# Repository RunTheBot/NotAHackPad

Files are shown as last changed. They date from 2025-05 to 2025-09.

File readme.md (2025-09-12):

# Not A HackPad

Basically a hack pad but with a lot more keys and a lot more LEDs. 

Made because a hackpad was too easy and small. Also I wanted to make it more like a keyboard than a hackpad. I also wanted to use a full pico.

## [BOM](https://docs.google.com/spreadsheets/d/1KeP3WG9XhRpOmTjCqM3hqRnjlMIbq6JLI_i9ZYCvpQc/edit?usp=sharing) | [CAD](https://cad.onshape.com/documents/e09ff01002204229131d6eeb/w/d4ffe006ec67723c6fe73dd8/e/5404e0c7dee7a93a5d70d53f) | [Journal](https://github.com/RunTheBot/NotAHackPad/blob/main/journal.md)




# Features
- 100 keys
- OLED Display
- Barrel Jack Power (Pico power is not enough)
- Auto Polarity Correcting Circuit for Barrel Jack
- 100 Neopixels
- External Power Supply for Neopixels (To run them at full brightness 😈)

# BOM

| Name | Quantity | Single Unit Price | Total Price | URL/LCSC | | |
|---|---|---|---|---|---|---|
| Electronics | | | | | | |
| C - LEDs | 100 | | $0.45 | C49678 | | |
| D - Rows/Cols | 100 | | $2.72 | C241939 | | |
| SK6812MINI | 100 | | $5.89 | C5149201 | | |
| schottky diode | 1 | | $0.29 | C85098 | | |
| IRF3205PBF | 2 | | $3.74 | C2561 | | |
| 5v 8A PSU | 1 | | $11.48 | https://www.aliexpress.com/item/4000521124523.html | | |
| IRF9540N | 2 | | $4.86 | C2575 | | |
| SSD1306 | 1 | | $3.10 | https://www.aliexpress.com/item/1005005301005280.html | | |
| Barrel Jack | 1 | | $1.84 | C381116 | | |
| BSS138 (Level Shifter) | 10 | | $0.42 | C82045 | | |
| 10K 0603 | 100 | | $0.11 | C98220 | | |
| Shipping/handling | | | $17.79 | | | |
| Misc | | | | | | |
| Solder Paste(Sn42Bi58-55g) | | | $9.78 | https://www.aliexpress.com/item/1005006055037674.html | | |
| Hot Plate (MECHANIC HT-10) | | | $33.99 | https://www.aliexpress.com/item/1005007493895441.html | | |
| Keys | | | | | | |
| Outemu Silent Grays | 1 | | | https://www.aliexpress.com/item/1005007052759423.html | | With uController |
| Key Caps - Printed | | | $0.00 | | | |
| JLC | | | | | | |
| PCB | 1 | $19.80 | $19.80 | | | |
| Shipping | 1 | $13.60 | $13.60 | | | |
| JLC duties | | | $3.57 | | | |
| | | | | | | |
| | | | $58.35 | CAD | | |
| | | | $75.08 | USD | | |
| | | | $117.71 | Total - USD | | |

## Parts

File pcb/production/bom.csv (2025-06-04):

Designator | Footprint | Quantity | Value | LCSC Part #
BRD1 | SSD1306-0.91-OLED-4pin-128x32 | 1 | SSD1306
C1, C10, C100, C11, C12, C13, C14, C15, C16, C17, C18, C19, C2, C20, C21, C22, C23, C24, C25, C26, C27, C28, C29, C3, C30, C31, C32, C33, C34, C35, C36, C37, C38, C39, C4, C40, C41, C42, C43, C44, C45, C46, C47, C48, C49, C5, C50, C51, C52, C53, C54, C55, C56, C57, C58, C59, C6, C60, C61, C62, C63, C64, C65, C66, C67, C68, C69, C7, C70, C71, C72, C73, C74, C75, C76, C77, C78, C79, C8, C80, C81, C82, C83, C84, C85, C86, C87, C88, C89, C9, C90, C91, C92, C93, C94, C95, C96, C97, C98, C99 | 0805 | 100 | C
D1, D10, D100, D11, D12, D13, D14, D15, D16, D17, D18, D19, D2, D20, D21, D22, D23, D24, D25, D26, D27, D28, D29, D3, D30, D31, D32, D33, D34, D35, D36, D37, D38, D39, D4, D40, D41, D42, D43, D44, D45, D46, D47, D48, D49, D5, D50, D51, D52, D53, D54, D55, D56, D57, D58, D59, D6, D60, D61, D62, D63, D64, D65, D66, D67, D68, D69, D7, D70, D71, D72, D73, D74, D75, D76, D77, D78, D79, D8, D80, D81, D82, D83, D84, D85, D86, D87, D88, D89, D9, D90, D91, D92, D93, D94, D95, D96, D97, D98, D99 | D_SOD-123 | 100 | D
D101, D102, D103, D104, D105, D106, D107, D108, D109, D110, D111, D112, D113, D114, D115, D116, D117, D118, D119, D120, D121, D122, D123, D124, D125, D126, D127, D128, D129, D130, D131, D132, D133, D134, D135, D136, D137, D138, D139, D140, D141, D142, D143, D144, D145, D146, D147, D148, D149, D150, D151, D152, D153, D154, D155, D156, D157, D158, D159, D160, D161, D162, D163, D164, D165, D166, D167, D168, D169, D170, D171, D172, D173, D174, D175, D176, D177, D178, D179, D180, D181, D182, D183, D184, D185, D186, D187, D188, D189, D190, D191, D192, D193, D194, D195, D196, D197, D198, D199, D200 | SK6812MINI-E | 100 | SK6812MINI
D205 | D_SMA_Handsoldering | 1 | D
J1 | BarrelJack_Horizontal | 1 | Barrel_Jack_Switch
Q1, Q4 | TO-220-3_Horizontal_TabDown | 2 | IRLZ44N
Q2, Q3 | TO-220-3_Horizontal_TabDown | 2 | IRF9540N
SW1, SW10, SW100, SW11, SW12, SW13, SW14, SW15, SW16, SW17, SW18, SW19, SW2, SW20, SW21, SW22, SW23, SW24, SW25, SW26, SW27, SW28, SW29, SW3, SW30, SW31, SW32, SW33, SW34, SW35, SW36, SW37, SW38, SW39, SW4, SW40, SW41, SW42, SW43, SW44, SW45, SW46, SW47, SW48, SW49, SW5, SW50, SW51, SW52, SW53, SW54, SW55, SW56, SW57, SW58, SW59, SW6, SW60, SW61, SW62, SW63, SW64, SW65, SW66, SW67, SW68, SW69, SW7, SW70, SW71, SW72, SW73, SW74, SW75, SW76, SW77, SW78, SW79, SW8, SW80, SW81, SW82, SW83, SW84, SW85, SW86, SW87, SW88, SW89, SW9, SW90, SW91, SW92, SW93, SW94, SW95, SW96, SW97, SW98, SW99 | SW_Cherry_MX_PCB_1.00u | 100 | SW_Push
U1 | RPi_Pico_SMD_TH | 1 | Pico

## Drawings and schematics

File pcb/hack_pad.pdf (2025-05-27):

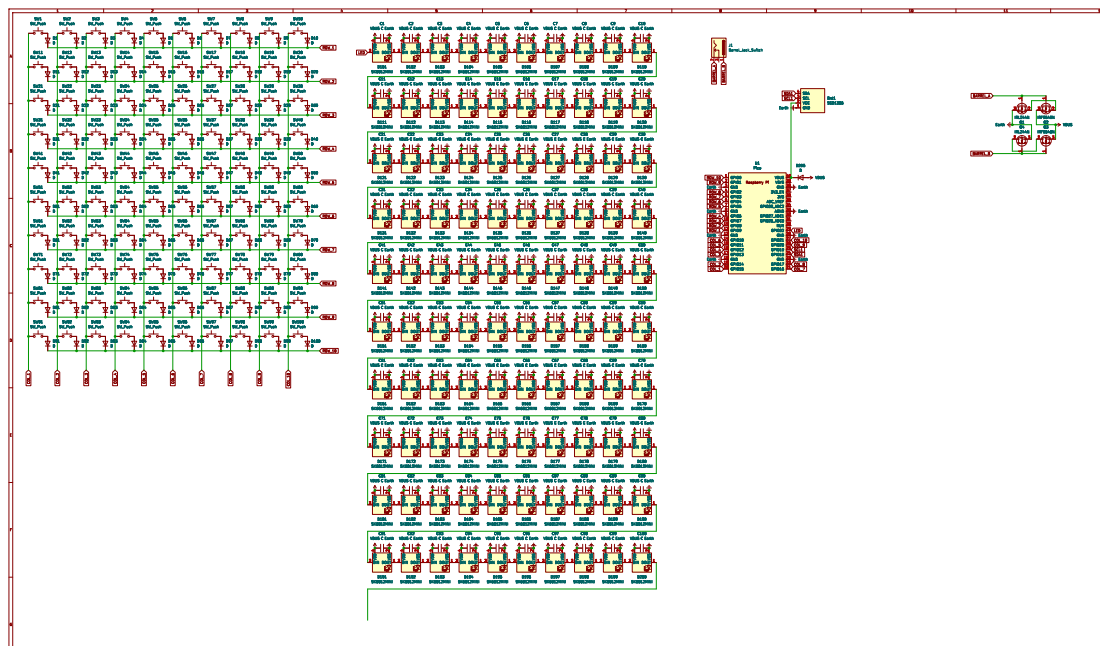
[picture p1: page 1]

2 DOUT 1 D116 SK6812MINI Earth VBUS Earth C5C VBUSC6C Earth Earth C7 VBUS C

2 DOUT 1 Earth VBUS Earth C5C VBUSC6C Earth Earth C7 VBUS C

2 DOUT 1 D110 SK6812MINI VBUS Earth VBUS C8C VBUSC10 Earth C Earth C9C

2 DOUT 1 VBUS Earth VBUS C8C VBUSC10 Earth C Earth C9C

2 DOUT 1 Earth D130 SK6812MINI DIN 3 VDD

2 DOUT 1 D104 SK6812MINI RGB DIN 3 VDD

2 DOUT 1 Earth D103 SK6812MINI DIN 3 VDD

2 DOUT 1 D103 SK6812MINI RGB DIN 3 VDD
RGB DIN 3 VDD

2 DOUT 1 VBUS D115 SK6812MINI DIN 3 VDD
D105 SK6812MINI DIN 3 VDD

2 DOUT 1 D105 SK6812MINI RGB DIN 3 VDD

2 DOUT 1 D107 SK6812MINI RGB DIN 3 VDD

2 DOUT 1 Earth D110 SK6812MINI DIN 3 VDD

2 DOUT 1 D112 SK6812MINI RGB DIN 3 VDD
LED

2 DOUT 1 D118 SK6812MINI RGB DIN 3 VDD

2 DOUT 1 Earth D118 SK6812MINI DIN 3 VDD

2 DOUT 1 D117 SK6812MINI RGB DIN 3 VDD

2 DOUT 1 D115 SK6812MINI RGB DIN 3 VDD

2 DOUT 1 D119 SK6812MINI RGB DIN 3 VDD
D119 SK6812MINI DIN 3 VDD

2 DOUT 1 D121 SK6812MINI C22 VBUS Earth VBUS C Earth C21C

2 DOUT 1 C22 VBUS Earth VBUS C Earth C21C

2 DOUT 1 D124 SK6812MINI VBUS Earth Earth VBUS C25 VBUS C

2 DOUT 1 VBUS Earth Earth VBUS C25 VBUS C

2 DOUT 1 VBUS C40 VBUS C Earth C30 Earth VBUS C Earth C29 VBUS C

2 DOUT 1 Earth D126 SK6812MINI DIN 3 VDD

2 DOUT 1 Earth D128 SK6812MINI DIN 3 VDD

2 DOUT 1 D122 SK6812MINI RGB DIN 3 VDD

2 DOUT 1 C34 VBUS C Earth D134 SK6812MINI DIN 3 VDD

2 DOUT 1 D137 SK6812MINI RGB DIN 3 VDD

2 DOUT 1 D132 SK6812MINI C32 Earth VBUS C Earth C31 VBUS C

2 DOUT 1 C32 Earth VBUS C Earth C31 VBUS C

2 DOUT 1 C33 VBUS C Earth D133 SK6812MINI DIN 3 VDD

2 DOUT 1 VBUS D135 SK6812MINI DIN 3 VDD

2 DOUT 1 D131 SK6812MINI RGB DIN 3 VDD

2 DOUT 1 D140 SK6812MINI RGB DIN 3 VDD
D140 SK6812MINI DIN 3 VDD

2 DOUT 1 VBUSC41C Earth D141 SK6812MINI DIN 3 VDD

2 DOUT 1 VBUS Earth VBUS Earth D142 SK6812MINI DIN 3 VDD

2 DOUT 1 D145 SK6812MINI VBUS Earth VBUS Earth

2 DOUT 1 D144 SK6812MINI RGB DIN 3 VDD

2 DOUT 1 D148 SK6812MINI RGB DIN 3 VDD

2 DOUT 1 D146 SK6812MINI RGB DIN 3 VDD

2 DOUT 1 D156 SK6812MINI RGB DIN 3 VDD

2 DOUT 1 D160 SK6812MINI RGB DIN 3 VDD

2 DOUT 1 VBUS VBUS Earth C58C Earth C59C

2 DOUT 1 VBUS Earth VBUS Earth C61C

2 DOUT 1 D152 SK6812MINI VBUS Earth VBUS Earth C62C

2 DOUT 1 VBUS Earth VBUS Earth C62C

2 DOUT 1 D154 SK6812MINI VBUS Earth C64 VBUS C Earth VBUSC65C Earth VBUS

2 DOUT 1 VBUS Earth C64 VBUS C Earth VBUSC65C Earth VBUSC66C

2 DOUT 1 VBUS D159 SK6812MINI DIN 3 VDD

2 DOUT 1 VBUSC70 Earth VBUS VBUS C Earth C67C Earth

2 DOUT 1 D161 SK6812MINI RGB DIN 3 VDD

2 DOUT 1 C72 VBUS C Earth D163 SK6812MINI DIN 3 VDD

2 DOUT 1 VBUS Earth D166 SK6812MINI DIN 3 VDD
D164 SK6812MINI DIN 3 VDD

2 DOUT 1 D166 SK6812MINI RGB DIN 3 VDD

2 DOUT 1 D165 SK6812MINI RGB DIN 3 VDD

2 DOUT 1 VBUS Earth D177 SK6812MINI DIN 3 VDD

2 DOUT 1 C77C Earth D168 SK6812MINI DIN 3 VDD

2 DOUT 1 D168 SK6812MINI RGB DIN 3 VDD

2 DOUT 1 VBUS Earth D170 SK6812MINI DIN 3 VDD

2 DOUT 1 D174 SK6812MINI VBUS C74C VBUS Earth C78 VBUS C

2 DOUT 1 VBUS C74C VBUS Earth C78 VBUS C

2 DOUT 1 VBUS Earth D172 SK6812MINI DIN 3 VDD

2 DOUT 1 VBUS Earth D171 SK6812MINI DIN 3 VDD

2 DOUT 1 VBUS Earth Earth VBUS VBUS C93C

2 DOUT 1 D179 SK6812MINI RGB DIN 3 VDD
D179 SK6812MINI DIN 3 VDD

2 DOUT 1 C87 VBUS C Earth VBUS Earth C88C

2 DOUT 1 VBUS Earth D187 SK6812MINI DIN 3 VDD

2 DOUT 1 D181 SK6812MINI RGB DIN 3 VDD

2 DOUT 1 D182 SK6812MINI RGB DIN 3 VDD

2 DOUT 1 D184 SK6812MINI RGB DIN 3 VDD

2 DOUT 1 Earth VBUS Earth D185 SK6812MINI DIN 3 VDD

2 DOUT 1 D187 SK6812MINI RGB DIN 3 VDD

2 DOUT 1 C96 VBUS VBUS Earth C

2 DOUT 1 Earth D198 SK6812MINI DIN 3 VDD

2 DOUT 1 D198 SK6812MINI RGB DIN 3 VDD

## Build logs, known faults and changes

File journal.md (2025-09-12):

Hours: 22h

# May 24

Hours: 1.5h

First pcb lol. I can't believe I made it this far without a single PCB. FRC, Infill ect.

Anyways, it's just a hackpad with a full pico and 100 buttons.

with 100 neopixels it gets complicated so barrel jack for power bc im not evan yu and i dont want to deal with USB PD.

I added a auto Polarity-correcting circuit so any barrel jack will work. 





# May 25
Hours: 2h

PCB layout done. Pretty basic. External PSU for LEDs and a RPI Pico.

I had to redo the schematic a lot of times because of kicad being weird. I crashed out.





# May 26

Hours: 0.5h

Added OLED


# Done!


# May 27
Hours: 3h

Case design done. pretty basic. I just wanted to get it done.

Firmware done. just macros in kmk.

Lots of modifactions to the PCB. Because of sizing issues.



# May 28
Hours: 2h
BOM and redoing the PCB yet again. Getting JLC to work. I used the wrong footprint for the diodes 😭.

# June 4
Hours: 1h
BOM changes. Remvoed PCBA

# June 6
Hours: 2h

I realized that I (may) need to level shift the data lines for the neopixels. Probably not needed but I will do it anyways since it is 100 neopixels and resistances + signal degradtaion might break things.

# June 27
Hours: 4h

Soldering all the LEDs and the microcontroller. 

Turns out I used way too much heat and too unevenly, so I warped the PCB and cracked multiple caps.

a

Warped ahhh PCB

I also had to bodge the wire two MOSFETs

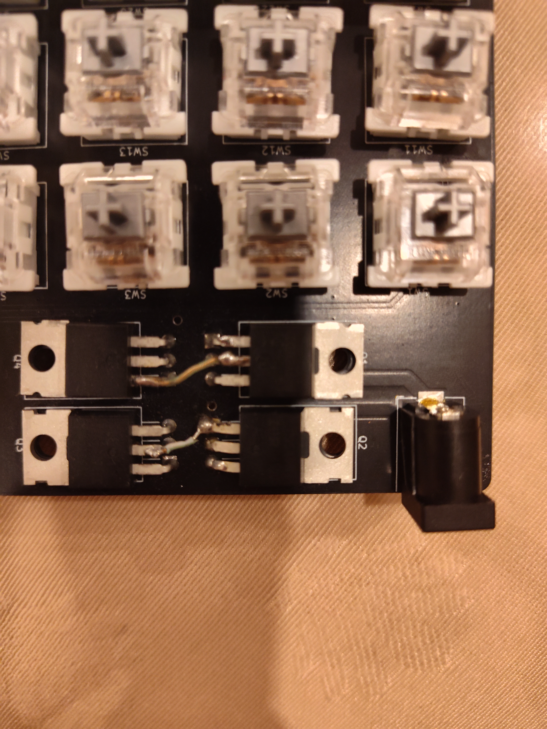
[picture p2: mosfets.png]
a


# July 29
Hours: 2
So I lowkey got very busy with exams and stuff then hackathons then Undercity.

I removed all the cracked caps. Realized that other stuff was very wrong about the PCB. Like I messed it up. not in kicad but in real life.

# July 30-31
Hours: 4
Fixing it up and debugging

So there are micro shorts everywhere, and when they heat up, they go from ~60k ohms to 1 ohms shorts, so rip. Freezer strats FTW. 

# Aug 2nd
It works bodge-wired except for a couple of keys. The case doesn't fit. Demo time.

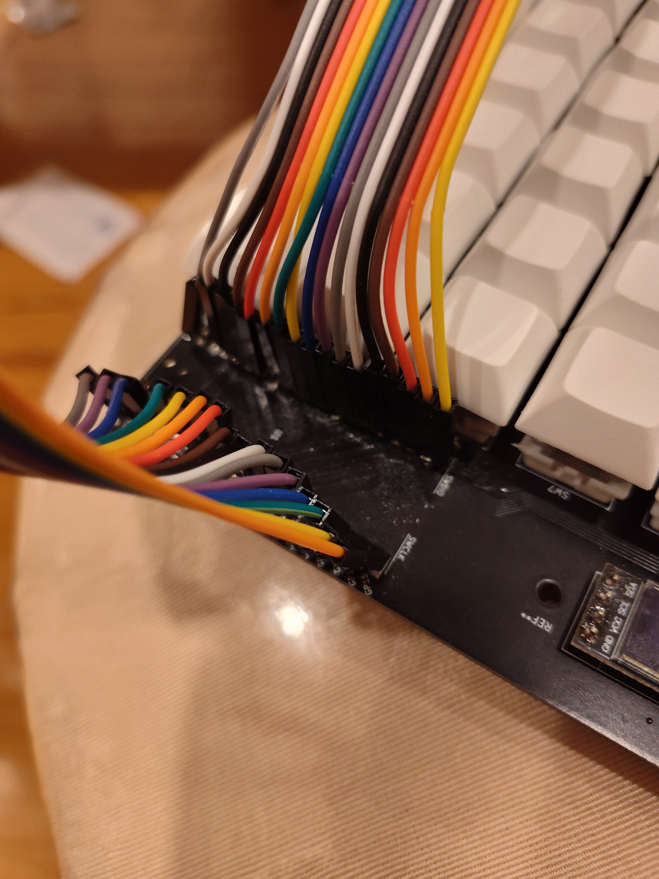
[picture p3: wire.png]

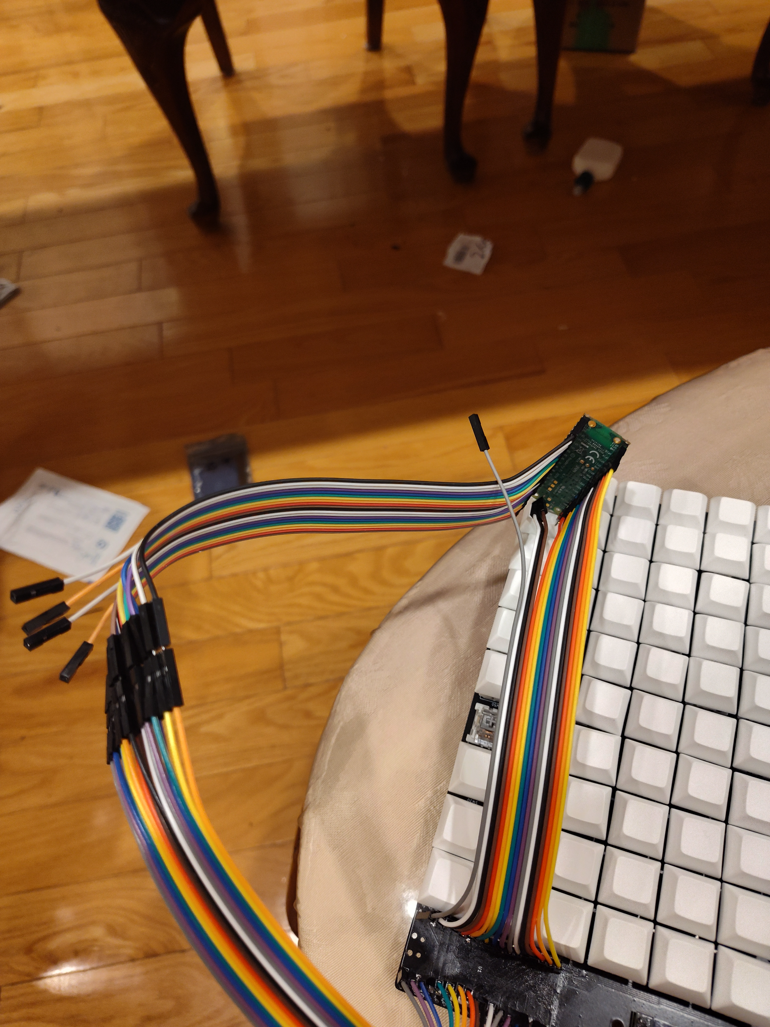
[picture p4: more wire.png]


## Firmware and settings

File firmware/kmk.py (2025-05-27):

from kmk.kmk_keyboard import KMKKeyboard
from kmk.scanners import DiodeOrientation
from kmk.keys import KC
from kmk.modules.layers import Layers
from kmk.modules.macros import Macros
from kmk.modules.holdtap import HoldTap
import neopixel
import board

keyboard = KMKKeyboard()

# Define pins
keyboard.col_pins = (board.GP15, board.GP14, board.GP13, board.GP12, board.GP11,
                     board.GP10, board.GP16, board.GP17, board.GP20, board.GP21)

keyboard.row_pins = (board.GP9, board.GP8, board.GP7, board.GP6, board.GP5,
                     board.GP4, board.GP3, board.GP2, board.GP1, board.GP0)

keyboard.diode_orientation = DiodeOrientation.COL2ROW

# Add modules
layers = Layers()
macros = Macros()
keyboard.modules = [layers, macros]

# Layer names
BASE = 0
PROD = 1
DEV = 2
GAME = 3
ART = 4

# RGB class for NeoPixel integration
class RGB:
    def __init__(self, keyboard, pin, pixel_count, rows, cols):
        self.kbd = keyboard
        self.pixels = neopixel.NeoPixel(pin, pixel_count, auto_write=False)
        self.rows = rows
        self.cols = cols
        # layer background colors
        self.layer_colors = {
            BASE: (255,   0,   0),  # red
            PROD: (  0, 255,   0),  # green
            DEV:  (  0,   0, 255),  # blue
            GAME: (128,   0, 128),  # purple
            ART:  (255, 255,   0),  # yellow
        }
        self.active_color = (255, 255, 255)  # white for keypress

    def after_matrix_scan(self):
        # 1) fill background
        layer = self.kbd.modules[0].active_layer
        bg = self.layer_colors.get(layer, (0, 0, 0))
        for i in range(len(self.pixels)):
            self.pixels[i] = bg
        # 2) highlight pressed keys
        for r in range(self.rows):
            for c in range(self.cols):
                if self.kbd.matrix[r][c]:
                    idx = r * self.cols + c
                    self.pixels[idx] = self.active_color
        self.pixels.show()

# Add RGB module
rgb = RGB(
    keyboard,
    board.GP22,
    len(keyboard.row_pins) * len(keyboard.col_pins),
    len(keyboard.row_pins),
    len(keyboard.col_pins),
)
keyboard.modules.append(rgb)

# Keymap
keyboard.keymap = [

    # 0: BASE LAYER (F1–F24)
    [
        KC.F1, KC.F2, KC.F3, KC.F4, KC.F5, KC.F6, KC.F7, KC.F8, KC.F9, KC.F10,
        KC.F11, KC.F12, KC.F13, KC.F14, KC.F15, KC.F16, KC.F17, KC.F18, KC.F19, KC.F20,
        KC.F21, KC.F22, KC.F23, KC.F24, KC.NO, KC.NO, KC.NO, KC.NO, KC.NO, KC.NO,
        KC.NO, KC.NO, KC.NO, KC.NO, KC.NO, KC.NO, KC.NO, KC.NO, KC.NO, KC.NO,
        KC.NO, KC.NO, KC.NO, KC.NO, KC.NO, KC.NO, KC.NO, KC.NO, KC.NO, KC.NO,
        KC.NO, KC.NO, KC.NO, KC.NO, KC.NO, KC.NO, KC.NO, KC.NO, KC.NO, KC.NO,
        KC.NO, KC.NO, KC.NO, KC.NO, KC.NO, KC.NO, KC.NO, KC.NO, KC.NO, KC.NO,
        KC.NO, KC.NO, KC.NO, KC.NO, KC.NO, KC.NO, KC.NO, KC.NO, KC.NO, KC.NO,
        KC.NO, KC.NO, KC.NO, KC.NO, KC.NO, KC.NO, KC.NO, KC.NO, KC.NO, KC.NO,
        KC.TRNS, KC.MO(PROD), KC.MO(DEV), KC.MO(GAME), KC.MO(ART), KC.NO, KC.NO, KC.NO, KC.NO, KC.NO
    ],

    # 1: PRODUCTIVITY LAYER
    [
        KC.LCTL(KC.C), KC.LCTL(KC.V), KC.LCTL(KC.Z), KC.LCTL(KC.LSFT(KC.Z)),  # Copy/Paste/Undo/Redo
        KC.WIN(KC.LSFT(KC.S)), KC.WIN(KC.DOT), KC.LALT(KC.TAB), KC.LCTL(KC.TAB),  # Snip, Emoji, AltTab
        KC.LCTL(KC.LSFT(KC.M)),  # Mute Mic
        KC.MACRO(0), KC.MACRO(1),  # Notepad, Terminal (macros below)
        *[KC.NO] * (100 - 11)
    ],

    # 2: DEV WORK LAYER
    [
        KC.LCTL(KC.LSFT(KC.B)), KC.F5, KC.LCTL(KC.SLASH),  # Build/Run, Comment
        KC.LCTL(KC.GRAVE), KC.LSFT(KC.LALT(KC.F)),         # Toggle terminal, Format
        KC.MACRO(2), KC.MACRO(3),  # Custom snippets, Git Pull/Push
        *[KC.NO] * (100 - 7)
    ],

    # 3: GAMING MACROS
    [
        KC.MACRO(4), KC.MACRO(5), KC.MACRO(6), KC.MACRO(7), KC.MACRO(8),
        *[KC.NO] * (100 - 5)
    ],

    # 4: CREATIVE / DESIGN LAYER
    [
        KC.LBRC, KC.RBRC,                 # Brush Size +/-
        KC.MACRO(9), KC.MACRO(10),        # Lock/Hide Layer
        KC.LCTL(KC.T), KC.LCTL(KC.J),     # Transform / Duplicate
        KC.F12, KC.B, KC.E,               # Render, Brush, Eraser
        *[KC.NO] * (100 - 9)
    ]
]

keyboard.macros = [
    # 0: Open Notepad (Windows Run shortcut)
    (0, [KC.WIN, KC.R], [KC.N, KC.O, KC.T, KC.E, KC.P, KC.A, KC.D, KC.ENTER]),

    # 1: Open Terminal
    (0, [KC.WIN, KC.R], [KC.C, KC.M, KC.D, KC.ENTER]),

    # 2: Insert Snippet
    (0, [], [KC.SLASH, KC.SLASH, KC.SPACE, KC.S, KC.N, KC.I, KC.P, KC.NEWLINE]),

    # 3: Git pull/push combo (as a placeholder, just types git pull)
    (0, [], [KC.G, KC.I, KC.T, KC.SPACE, KC.P, KC.U, KC.L, KC.L, KC.ENTER]),

    # 4: Quick Cast (simulate combo)
    (0, [], [KC.D, KC.D]),

    # 5: Double Tap Macro
    (0, [], [KC.SPACE, KC.SPACE]),

    # 6: Combo Tap
    (0, [], [KC.X, KC.W, KC.Y]),

    # 7: Inventory key
    (0, [], [KC.I]),

    # 8: Chat Command
    (0, [], [KC.SLASH, KC.D, KC.A, KC.N, KC.C, KC.E, KC.ENTER]),

    # 9: Lock Layer (e.g. L)
    (0, [], [KC.L]),

    #10: Hide Layer (e.g. H)
    (0, [], [KC.H]),
]

if __name__ == '__main__':
    keyboard.go()

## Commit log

2025-05-25 Add lock file for autosave feature in hack_pad PCB design
2025-05-26 Add initial journal entries and PCB lock file
    - Created a journal.md to document the progress of the first PCB project, including details about the design, components, and layout.
    - Added images of the PCB layout and components such as the RPI Pico and OLED.
    - Introduced a lock file for the schematic to track user information.
    [hack_pad.kicad_sch]
2025-05-26 Add lock file for hack_pad PCB with hostname and username information
    [hack_pad.kicad_sch]
2025-05-28 Done - minus bom
    [hack_pad.kicad_sch]
2025-05-28 Update BOM link in README to the correct spreadsheet
2025-06-04 Add PCB position data and autosave lock file
    - Introduced a new CSV file containing detailed positions for various components on the PCB, including designators, coordinates, rotation, and layer information.
    - Created an autosave lock file to manage PCB design sessions, ensuring that user session data is preserved.
2025-06-04 Add BOM file for PCB production with component details and specifications
    [bom.csv, bom.good.csv, designators.csv]
2025-06-07 Level Shifter
    [NotAHackPad - BOM.csv, hack_pad.kicad_sch]
2025-06-08 fix bom
2025-06-08 Refactor code structure for improved readability and maintainability
    [hack_pad.kicad_sch]
2025-06-09 Add lock file for PCB project with hostname and username information
2025-06-09 Add BOM file for PCB project with detailed component list and pricing
    [NotAHackPad - BOM - LCSC.csv]
2025-06-10 Update journal with total hours and BOM changes
